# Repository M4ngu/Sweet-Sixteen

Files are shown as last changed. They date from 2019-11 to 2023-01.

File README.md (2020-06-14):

# Sweet-Sixteen
Eurorack module based in the [16n faderbank][16n-faderbank/16n]. 

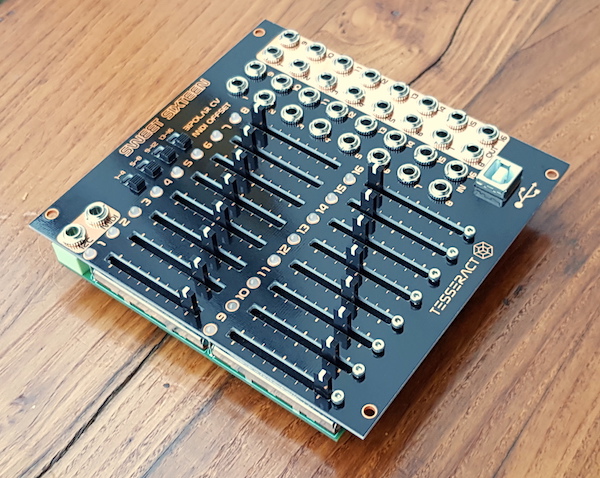
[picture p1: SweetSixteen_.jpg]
Sweet Sixteen


## The following changes were made to the original hardware:

-The PCB layout has been made from scratch, so it's totally different, with 0603 passives instead of 0805.

-A power section has been added to work within the eurorack modular synth format, with diode protection and the option to power the Teensy with an internal 5V LDO or the eurorack 5V rail (selectable with a jumper on the back of the module). The voltage to feed the faders now comes from a dedicated voltage regulator, more stable and precise than most USB voltage sources.

-16 Inputs has been added. A "default voltage" is normalled to the input jacks, so when something is plugged in, that normalization is broken, being the incomming CV attenuated by the fader. This adition makes the module to work also as 16 attenuators, Cv to Midi, Cv to i2C...

-The op-amps circuit has been modiffied, being TL074s for the CV outs and MCP6004s for the circuit that prepares the voltages to be read by the Teensy. In this version the MCP6004 are powered with 3,3V & GND (instead of the original 5V), the rail-to-rail characteristic of those op-amps provides voltage protection to the Teensy. That is specially handy for the CV inputs, as any voltage plugged in, will be limited to 3,3v by the MCP6004s. Another important modification in this part of the circuit is the addition of negative voltage references and that now is a summing inverting gain circuit (for that reason the FLIP option in the firmware is necessary for this version of the hardware, as in the minimum position of the fader the voltage readed by the Teensy will be 3,3V and in the max position it will be 0V). The TL074s are powered by +12V & -12V.

-Four slide switches has been added to swap the voltage reference (1 for every 4 faders, there was no room for 16 switches). The reason is to allow negative voltages to be coorectly converted to midi CC (or i2C). In the normal position a 0V input is traduced as minimum CC value, with the switch turned up the voltage reference is -2,5V (instead of -5V) that means that 0V input correspond to the center position of the MidiCC, positive voltages will increase the value while negative ones will decrease it.

-The output voltage of the faders (that "default voltage" normalled to the jacks) has been increassed to 8v, the original 5v seems to be not enough to work in eurorack, like to wide open-close the cutoff of a filter etc. I decided to go 8v instead of 10v because of the CV inputs. If the circuit that prepares the voltages comming from the faders to be readed by the Teensy is expecting 10v then it will be impossible to cover all the range of a MidiCC with an LFO which is ±4v (or 8v pp). For the contrary, if that circuit is expecting 8V it can not only cover the whole Midi CC range but also allows saturating the waveform if the voltage source has over 8V pp (like a 10V envelope or a ±5V LFO).

-16 bicolor leds has been added in parallel with the CV out, allowing visual feedback of what's going on each track, specially handy when using the CV inputs.

-USB type B connector pcb mounted has been also added. Those connectors are much stronger than mini or micro ones, the USB 5V pin is not connected, this way you can update the firmware of the Teensy without powering off the module.

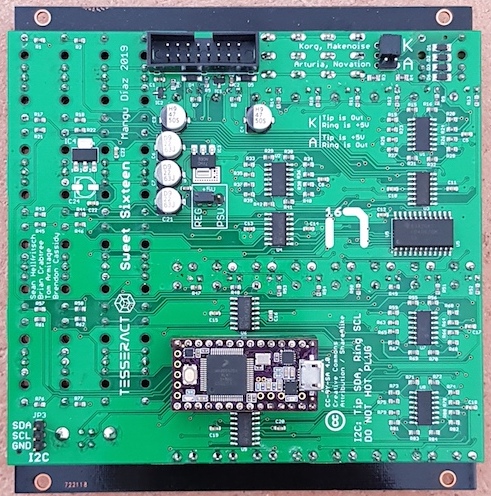
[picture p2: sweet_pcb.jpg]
PCB


Various versions of the firmware are available, all them derived from the 16n by Tom Armitage.

Manual and build guide:

https://www.tesseractmodular.com/manuals/sweet-sixteen-manual

## [firmware](firmware/)

## [hardware](hardware/)

### There are 16 faders/channels, which can be used as:

 -Midi controller.  
 -Manual CV generator (0 to 8v range).  
 -Attenuator.  
 -CV to Midi CC.  
 -i2C controller.  
 -CV to i2C data.  

### Features:

 -16 inputs.  
 -16 outputs.  
 -16 faders.  
 -16 bi-color leds to show what's going on in every channel.  
 -Midi trs out.  
 -Jumpers on the back to swap between 'Arturia/Novation'  and 'Korg/Makenoise' Midi trs standards.  
 -USB Midi out (connector type B, usb midi class compliant device).  
 -4 switches to enable bi-polar CV to Midi/i2C conversion (one for every 4 channels).  
 -i2C via mini jack on front panel and pin header on the back of the module.  

## Credits
This is a derivative work of the [16n faderbank][16n-faderbank/16n].  
Based on original work by [Brian Crabtree][tehn] and Sean Hellfritsch.  
Minijack MIDI, I2C circuitry and CV outputs by [Tom Armitage][infovore].  
Firmware by [Brian Crabtree][tehn], [Tom Armitage][infovore], and [Brendon Cassidy][bpcmusic].  
Eurorack conversion, hardware & firmware mods by Mangu Díaz 2019.  

## Licensing

Panels and electronic schematics/layouts/gerber files are licensed under
[Creative Commons Attribution Share-Alike 4.0][ccbysa].

Firmware is licensed under the [MIT License][mitlicense].

[linespost]: https://llllllll.co/t/sixteen-n-faderbank/3643
[tehn]: https://github.com/tehn
[bpcmusic]: https://github.com/bpcmusic
[infovore]: https://github.com/infovore
[octobom]: https://octopart.com/bom-tool/unJxkzvR
[ccbysa]: https://creativecommons.org/licenses/by-sa/4.0/
[mitlicense]: https://opensource.org/licenses/MIT
[16n-faderbank/16n]: https://github.com/16n-faderbank/16n

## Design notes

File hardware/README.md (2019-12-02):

If you want to order pcbs yourself make sure you have a valid replacement for the faders, the ones I use may have a weird pinout. You can also edit the board in order to use your desired fader model.

The voltage of the faders (when there's nothing plugged in) could be easy modified by replacing the IC4 for another LDO and changing the value of the summing resistors in the MCP6004 circuits, in order to get 3,3v (or close) from the LDO once passes throught the op-amp.

The formula is pretty simple: 

Vin * (RFB / RIN) = 3,3 

In this case the IC4 LDO is an 8V regulator, so: 

8v * (33k / 80,6k) = 3,27v

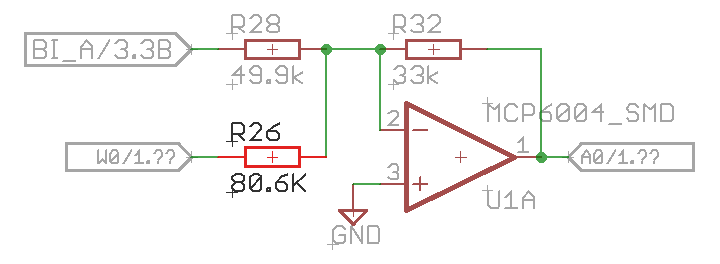
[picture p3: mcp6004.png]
MCP6004 circuit


Keep in mind that if you change the 33k feedback resistor for other value, the summing resistors for the voltage reference must be also adapted with the same criteria: 

5v * (33k / 49,9k) = 3,3v

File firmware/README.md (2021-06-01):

## Sweet_3

derived from the 16n 2.0.1 by Tom Armitage. 

midiCC, midi channels, master i2c and calibration settings can be done in the web editor so compiling your own firmware is not necessary, just download the HEX file and flash it with the Teensy loader.

https://16n-faderbank.github.io/editor/

changes from the original 16n 2.0.1:
  
  -channel numbers are not reversed if the 'rotate' is active
  
  -calibration of the high value is now possible when the 'rotate' is active

  -added pitchBend ( by selecting midiCC 127 )
  
  -added support for GESS ( Gate Expander for Sweet Sixteen ) which makes midi notes with gates & buttons in GESS
  
    About the GESS feature:
    
    -every button/gate in will create a midi note in the TRS & USB midi outs
    
    -the pitch and velocity can be a fixed value or CV controlled (upper 8 faders & CV inputs for note value, lower 
    row of fader & CV for velocity)
    
    -8 presets
    
    -press the function button (next the USB port) to activate the 'load preset', any of the 8 buttons will load it.
    
    -press the function button while pressing any of the 8 GESS buttons will save a preset, the position of the 
    faders will determine the preset values (upper row for pitch, lower row  for velocity) and if any of the faders
    is at minimum position, then that value would be read in real time. So if you save a preset with the fader 2 & 9 
    fully down, the midi notes generated by gates in the GESS input 2 will be controlled by the fader & CV 2, and the
    velocity of the notes generated by the gate input 1 will be CV controlled by fader & CV 9. None of those faders 
    will send the usual midiCC while being used for midi note or velocity.

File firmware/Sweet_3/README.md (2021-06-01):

# Sweet_3 Firmware

Designed to run on a Teensy 3.2; 

This README serves as a guide for **developing** and **compiling** your own versions of the firwmare. The recommended method for putting firmware onto a Sweet Sixteen is to use Teensy Loader directly. 

If you are interested in compiling your own firmware, or hacking on it, read on!

## Requirements

- Latest Teensyduino install.
- `ResponsiveAnalogRead` library
- `CD74HC4067` library

## Compilation

- You **must** compile this with Tools->USB type set to **MIDI**. (**Serial+MIDI** may have issues with certain devices you connect to).
- Be sure that the board speed is set to 120mhz (overclock) for maximum repsonsiveness.
- If you're having issues compiling related to MIDI libraries or code: make sure your Arduino `libraries` folder doesn't have any old versions of weird MIDI libraries in. The MIDI library should be installed by default via Teensyduino; otherwise, if you have the latest version of the 47effects MIDI library in your Libraries Manager, that'll also behave. It turns out that older versions in the legacy `libraries` folder sometimes lead to conflicts.

## Customisation and configuration

As of 16n firmware 2.0.0, you no longer should do ANY configuration through the Arduino IDE. Most configurations are conducted from a web browser, using the [16n editor][editor]

The Sweet Sixteen will be initialised to a set of default settings (All outputs for TRS and USB set to MIDI channel 1, CCs 32-47, I2C set to Leader). Once this is done, connect over USB, and go to the [editor][editor] in Google Chrome; you will be able to see the current configuration, edit the configuration, and transmit the new config to your device. You will likely need to customise the maximum fader value calibrations.

Note that if you do change any config related to I2C, you should power-cycle the 16n before it will be picked up.

Some options _do_ remain in `config.h`; they are for developers to specify options that are likely to need setting once, or adjusting during the development process:

In `config.h`

// define startup delay in milliseconds

// for ER-301, which needs to be ON before Sweet Sixteen to connect via i2c

#define BOOTDELAY 10000

// uncomment this to allow PITCHBEND for controller 127:

#define PITCHBEND 1

// allow the Tsesseract Modular GESS & midi note implementation:

#define GESS 1

// default GESS settings (midi note, velocity and channel):

byte _nNote[8] = { 30, 40, 50, 60, 70, 80, 90, 100 };

byte _nVelocity[8] = { 120, 120, 120, 120, 120, 120, 120, 120 };

byte _nChannel[8] = { 1, 2, 3, 4, 5, 6, 7, 8 };

```C
#define DEBUG 1
```

will log debug messages to the serial port.

```C
#define DEV 1
```

will restrict the faderbank to its first channel. Designed for breadboard development; almost certainly not of interest.

## Memory Map

Configuration is stored in the first 80 bytes of the on-board EEPROM. It looks like this:

Addresses 0-15 are reserved for configuration flags/data.

FADERMAX and FADERMIN are 14-bit numbers; as such, they are stored in two bytes as MSB and LSB; the actual number is calculated by `(MSB << 8) + LSB`

+---------+--------+------------------------------------+

| Address | Format |            Description             |

+---------+--------+------------------------------------+

| 0       | 0/1    | LED on when powered                |

| 1       | 0/1    | LED blink on MIDI data             |

| 2       | 0/1    | Rotate controller outputs via 180º |

| 3       | 0/1    | I2C Master/Follower                |

| 4,5     | 0-127  | FADERMIN lsb/msb                   |

| 6,7     | 0-127  | FADERMAX lsb/msb                   |

| 8-15    |        | Currently vacant                   |

+---------+--------+------------------------------------+

| 16-31   | 0-15   | Channel for each control (USB)     |

| 32-47   | 0-15   | Channel for each control (TRS)     |

| 48-63   | 0-127  | CC for each control (USB)          |

| 64-79   | 0-127  | CC for each control (TRS)          |

+---------+--------+------------------------------------+

EEPROM address 100-115 is used for GESS presets

## LICENSING

see `LICENSE`

[load-firmware]: https://github.com/16n-faderbank/16n/wiki/Firmware:-installation-instructions
[editor]: https://16n-faderbank.github.io/editor

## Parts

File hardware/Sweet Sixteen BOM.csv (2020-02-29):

Qty | DESIGNATOR | FOOTPRINT | COMMENT | Description | MF
2 | R3, R4 | 0805-R | 47 | RESISTOR, European symbol
2 | R5, R6 | 0603-R | 270 | RESISTOR, American symbol
16 | R1, R2, R17, R18, R21, R22, R43, R44, R45, R46, R57, R58, R61, R62, R76, R77 | 0603-R | 1K | RESISTOR, European symbol
16 | R7, R8, R9, R10, R11, R12, R13, R14, R47, R48, R49, R50, R51, R52, R53, R54 | 0603-R | 10k | RESISTOR, European symbol
16 | R15, R16, R29, R30, R31, R32, R41, R42, R55, R56, R69, R70, R71, R72, R83, R84 | 0603-R | 33k | RESISTOR, European symbol
16 | R19, R20, R27, R28, R33, R34, R39, R40, R59, R60, R67, R68, R73, R74, R81, R82 | 0603-R | 49.9k | RESISTOR, European symbol
1 | R26 | 0603-R | 50K | RESISTOR, European symbol
15 | R23, R24, R25, R35, R36, R37, R38, R63, R64, R65, R66, R75, R78, R79, R80 | 0603-R | 80.6k | RESISTOR, European symbol
11 | C5, C10, C11, C12, C13, C14, C15, C16, C18, C19, C20, C8, C17, C9, C22 | 0603-C | 100n | CAPACITOR, European symbol
1 | C23 | 0603-C | 330n | CAPACITOR, American symbol
2 | C1, C2 | 0603-C | 470n | CAPACITOR, American symbol
1 | C24 | PANASONIC_C | 10u | POLARIZED CAPACITOR, American symbol
3 | C6, C7, C21 | PANASONIC_D | 22u | POLARIZED CAPACITOR, American symbol
2 | C3, C4 | PANASONIC_D | 47u | POLARIZED CAPACITOR, American symbol
4 | D1, D2, D3, D6 | SOD-123 | 1N4148
2 | D4, D5 | SOD123 | 1N5819 | DIODE
1 | IC3 | SOT223 | LM1117-5 | 800mA and 1A Low Dropout (LDO) Positive Regulator
1 | IC1 | DBZ_R-PDSO-G3 | LM4040C25 | PRECISION MICROPOWER SHUNT VOLTAGE REFERENCE
1 | IC2 | DBZ_R-PDSO-G3 | LM4040c50 | PRECISION MICROPOWER SHUNT VOLTAGE REFERENCE
1 | IC4 | SOT223 | UA78M08DCY | 8V POSITIVE-VOLTAGE REGULATORS
1 | U5 | SOIC127P1030X265-24 | CD74HC4067SM96 | 16-channel analog MUX
4 | U1, U2, U7, U8 | SO14 | MCP6004_SMD | Generic Quad Op Amp
4 | U3, U4, U6, U9 | SO14 | TL074_SMD | Generic Quad Op Amp
1 | TENSY3.2 | TEENSY_3.0-3.2&LC_DIL | TEENSY_3.1-3.2_DIL | Teensy 3.1 or 3.2 in a DIL Layout.
34 | J1, J2, J3, J4, J5, J6, J7, J8, J9, J10, J11, J12, J13, J14, J15, J16, J17, J18, J19, J20, J21, J22, J23, J24, J25, J26, J27, J28, J29, J30, J31, J32, J33, J34 | WQP_PJ_301M6 | PJ301_THONKICONN6
1 | X1 | KUSBVX-BS1N | KUSBVX-BS1N | USB B-type Receptacle Vertical, 4 Position, Through Hole
2 | +5V, JP3 | 1X03 |  | PIN HEADER
1 | JP1 | 2X03 |  | PIN HEADER
16 | TM1, TM2, TM3, TM4, TM5, TM6, TM7, TM8, TM9, TM10, TM11, TM12, TM13, TM14, TM15, TM16 | SLIDEPOT-45 |  | Sliding potentiometers
4 | S1, S2, S3, S4 |  |  | SLIDING SWITCH
16 | LED1, LED2, LED3, LED4, LED5, LED6, LED7, LED8, LED9, LED10, LED11, LED12, LED13, LED14, LED15, LED16 | LED3MM |  | BI-COLOR LED
1 | SV1 | ML16 |  | HARTING

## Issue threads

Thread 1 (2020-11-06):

Usb undefined

synnys, 2020-11-06:
I’m flashed my teensy, the sweet sixteen is working fine. But when I connect the usb b port to my computer, my Mac sees it as “undefined” and it’s not receiving any midi. Any idea what this could be? The flashing went fine

M4ngu, 2020-11-06:
Hi there, did you set the USB as MIDI?
and CPU to 120mhz?
https://www.tesseractmodular.com/manuals/sweet-sixteen-manual#h.p_RE-CxcQ3ERIl
let me know if this helps
Mangu Díaz - Tesseract Modular
https://www.tesseractmodular.com/
https://www.facebook.com/Tesseract-Modular-146727136274298
https://www.modulargrid.net/e/vendors/view/713
https://www.instagram.com/mangudiaz/

El vie., 6 nov. 2020 a las 21:39, synnys (<notifications@github.com>)
escribió:

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

synnys, 2020-11-06:
Yes I did set it as usb midi @ 120mhz

Ruben Hulzebosch

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

synnys, 2020-11-06:
do I need to install additional libraries in teensyduino? Because it doesn't error on compile..

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
these .h includes have a different color though, not sure if that's supposed to be like that?

M4ngu, 2020-11-07:
to compile it you have to download all files in the folder, not just the
.ino file,
those files included in the folder are the green ones,
the other are libraries,
if it compiles with no errors it's all correct, you don't need to install
any extra library or download any file,

Which firmware are you installing?
my recommendation is the 2.0.1 version modded for SweetSixteen,  because
the settings can be modified with web application,
unless you have the GESS or you need pitch bend, in that case the other
firmwares would be better,
I think there is a compiled version of that, let me know if you can't find
it
all the best
Mangu Díaz - Tesseract Modular
https://www.tesseractmodular.com/
https://www.facebook.com/Tesseract-Modular-146727136274298
https://www.modulargrid.net/e/vendors/view/713
https://www.instagram.com/mangudiaz/

El vie., 6 nov. 2020 a las 23:15, synnys (<notifications@github.com>)
escribió:

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

synnys, 2020-11-08:
I cloned the whole repository so I did have all the files, not just the .ino file.
I uploaded this firmware: https://github.com/M4ngu/Sweet-Sixteen/tree/master/firmware/Sweet_mkII/_16n_faderbank_firmware_Sweet_mkII
(since I have an mk2)
I had no compiler errors and the flashing went fine, I just can't seem to figure out why it's not detected as a USB midi device. It just sees it as undefined... If you have a compiled .hex I could try that would be great

Cheers.

synnys, 2020-11-08:
Hmm come to think of it, I suddenly have a feeling i know what might have gone wrong...
In the BOM this was the USB connector: https://nl.mouser.com/datasheet/2/670/uj2_bv_1_th-1779281.pdf
However, that was not in stock so I ordered this one in the meantime, while the other in back stock would be delivered: https://nl.mouser.com/ProductDetail/530-SS-52300-002

I just saw that it has a reverse orientation compared to the one in the BOM, so I suspect the pinout is upside down then as well....

M4ngu, 2020-11-08:
so you have the GESS expander correct?
because if not I'd recommend the 2.0.1 version.

I thought all those USB connectors had the same pinout, anyway I can't see
that info in the specs sheet of one of them :-(
but as you say, the orientation is different, so pins may be also
different, but can't say 100% sure.

To be sure that the USB is working what I do is just to flash the Teensy
using the front USB port, with the module powered, if it flashes ok then
the USB is going fine,
the computer should detect it as a "16n" midi device if everything is
correct.

there you have a compiled HEX from that mkII version,

let me know if it helps

 best
Mangu Díaz - Tesseract Modular
https://www.tesseractmodular.com/
https://www.facebook.com/Tesseract-Modular-146727136274298
https://www.modulargrid.net/e/vendors/view/713
https://www.instagram.com/mangudiaz/

El dom., 8 nov. 2020 a las 10:40, synnys (<notifications@github.com>)
escribió:

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

synnys, 2020-11-20:
installed new USB connector, since i foolishly damaged the original one. (Desoldering was a drama for some reason)
Installed the 2.0.1 firmware, all is workingas it should now and the web-editor is working too.
Case closed!
Thanks for the help.

Ruben

Closed 2020-11-20.

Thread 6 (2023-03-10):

MIDI to CV

Bubobubobubobubo, 2023-03-10:
Hi,

Is it possible to reprogram the Sweet Sixteen to act as a MIDI to CV converter? I would like to use the same CC values but in the other direction :) Meaning, a CC from 0 to 127 converted into a 0-8V on the corresponding output. If so, could you provide some guidance on the process to rewrite the code to do so?

Thanks a lot, nice module!

M4ngu, 2023-03-11:
The digital part of this module controls only the MIDI and the i2C data. The faders, CV in & out circuit is fully analog, so modifications like changing the output voltage range can’t be done via firmware.
This module can do CV to midi (among many other functions) NOT midi to CV.

Bubobubobubobubo, 2023-03-11:
OK! Thanks!

Closed 2023-03-11.

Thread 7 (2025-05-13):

GESS i2c "0x00" shown on ES Disting NT

zstadl, 2025-05-13:
Hi there,

I'm having a hard time getting the GESS to work via i2c with my disting NT. The SW16 works fine with the disting NT. I get the messages on the disting's i2c monitor with the following format when I move a fader: 0x11 0x... ...x... ...x... However, when I press a button on the GESS i get the following on the Disting NT: 0x00.

It seems like the GESS doesn't send messages that the Disting NT can read. Also, when inspecting your firmware (correct me if I'm wrong) the GESS button midi to i2c messaging only work on the ER301: https://github.com/M4ngu/Sweet-Sixteen/commit/ed8b34c4b99a08bfd41c659a50852e556b334f12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

What do I need to change in order to make the GESS button i2c thingy work for the Disting NT?

Thx a lot!

ralbring, 2025-05-13:
Oh i think thats not so easy. I dosent tested or programmed this for disting NT. there are more problems.
1) The code must be compiled with the config.h option GESS 1. Default is off!
2) The Adresses for the disting at the i2c bus must inserted and used in the code and changed so that the message and variable er301Present is set to true.
If the code is not compiled with Option GESS or the address to the slave at the i2c bus ist correct, so that this is initilized no messege will be go out.

The first think that i woud try is to change the i2c address so that is correct and the initilizing part foud the device. All other stuff must be changed later and meybe it is a god style to bring the new constants for the disting into the code.

zstadl, 2025-05-13:
thanks a lot for the answer.

I followed your steps:
on config.h:
```
// allow the Tsesseract Modular GESS & midi note implementation:
#define GESS 1

// treat a Disting NT on the bus exactly like the ER-301 expander:
static const bool    er301Present     = true;   // enable GESS at compile time
static const uint8_t er301I2Caddress  = 0x31;   // Disting NT’s default I²C address
```

on the Sweet_3.ino I introduced a new i2c channel:
`#define TO_GATE 0x20 `

and applied it under the doMidiWrite section:
```
#ifdef GESS
    // Midi Note
    if ((q > 7) && (_G[q - 8] != old_G[q - 8])) // only if the gate input has changed we do this:
    {
      k = ( q - 8) ;
      if ( _G[k] == LOW ) //note ON
      {
        if (nNote[k] == true) // taking the note value from the upper row of faders instead of a fixed value
        {
          _nNote[k] = lastMidiValue[k];
        }
        if (nVelocity[k] == true) // taking the midi velocity from the lower row instead instead of a fixed value
        {
          _nVelocity[k] = lastMidiValue[q];
        }
        MIDI.sendNoteOn(_nNote[k], _nVelocity[k], _nChannel[k] ); // at the moment channels are 1 to 8 preassigned
        usbMIDI.sendNoteOn(_nNote[k], _nVelocity[k], _nChannel[k] );
        // ER-301
        if (er301Present) {
          // https://github.com/odevices/er-301/blob/develop/mods/teletype/Dispatcher.cpp
          // SC.TR 1-n α --> Set TR value to α (0/1)
          // commandTRSet(delay, getPort(msg), getValue(msg));
          sendi2c(er301I2Caddress, 0, TO_GATE, q - 8, 1);
        }

      }
      else //Note Off
      {
        MIDI.sendNoteOff(_nNote[k], _nVelocity[k], _nChannel[k] );
        usbMIDI.sendNoteOff(_nNote[k], _nVelocity[k], _nChannel[k] );
        if (er301Present) {
          sendi2c(er301I2Caddress, 0, TO_GATE, q - 8, 0);
        }

      }
      old_G[k] = _G[k];
    }  //end of midi note code
#endif
```

Good News: i2c monitoring on the Disting show "0x20"!
Bad news: That's all I see. No: "q - 8, 1" or "q - 8, 0".

Do you have an idea why?

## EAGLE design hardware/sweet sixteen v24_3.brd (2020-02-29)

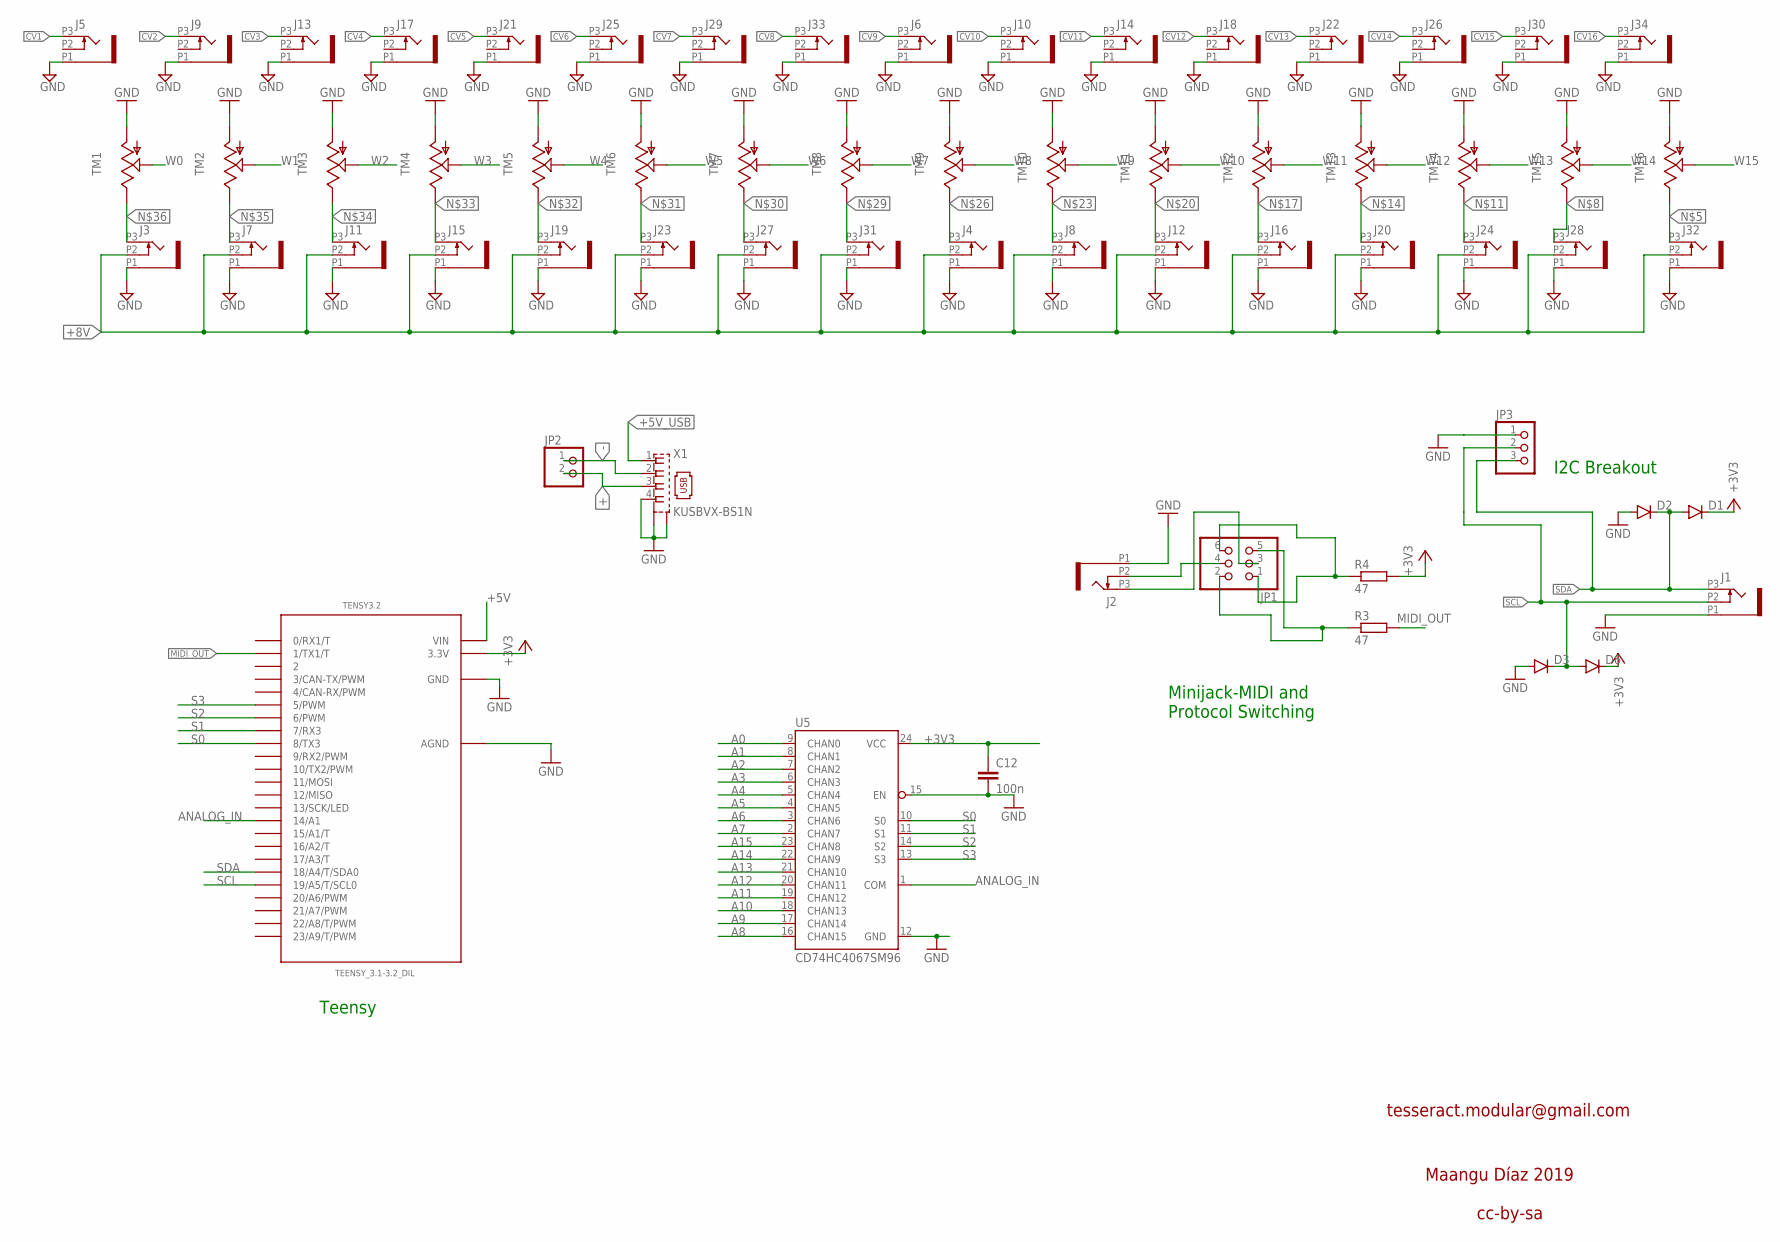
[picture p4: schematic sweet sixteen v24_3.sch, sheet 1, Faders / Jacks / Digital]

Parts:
C12: 100n; C0603
D1, D2, D3, D6: DIODESOD123; SOD-123
J1, J2, J3, J4, J5, J6, J7, J8, J9, J10, J11, J12, J13, J14, J15, J16, J17, J18, J19, J20, J21, J22, J23, J24, J25, J26, J27, J28, J29, J30, J31, J32, J33, J34: PJ301_THONKICONN6; WQP_PJ_301M6
JP1: PINHD-2X3; 2X03
JP2: PINHD-1X2; 1X02
JP3: PINHD-1X3; 1X03
R3, R4: 47; R0805
TENSY3.2: TEENSY_3.1-3.2_DIL; TEENSY_3.0-3.2&LC_DIL
TM1, TM2, TM3, TM4, TM5, TM6, TM7, TM8, TM9, TM10, TM11, TM12, TM13, TM14, TM15, TM16: TRIMSLIDE45; SLIDEPOT-45
U5: CD74HC4067SM96; SOIC127P1030X265-24
X1: KUSBVX-BS1N

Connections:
+: JP2.2, X1.3
+3V3: C12.1, D1.C, D6.C, R4.2, TENSY3.2.3.3V, U5.24 (VCC); also elsewhere on the board
+5V: TENSY3.2.VIN; also elsewhere on the board
+5V_USB: X1.1
+8V: J3.P2 (2), J4.P2 (2), J7.P2 (2), J8.P2 (2), J11.P2 (2), J12.P2 (2), J15.P2 (2), J16.P2 (2), J19.P2 (2), J20.P2 (2), J23.P2 (2), J24.P2 (2), J27.P2 (2), J28.P2 (2), J31.P2 (2), J32.P2 (2); also elsewhere on the board
-: JP2.1, X1.2
A0: U5.9 (CHAN0); also elsewhere on the board
A1: U5.8 (CHAN1); also elsewhere on the board
A2: U5.7 (CHAN2); also elsewhere on the board
A3: U5.6 (CHAN3); also elsewhere on the board
A4: U5.5 (CHAN4); also elsewhere on the board
A5: U5.4 (CHAN5); also elsewhere on the board
A6: U5.3 (CHAN6); also elsewhere on the board
A7: U5.2 (CHAN7); also elsewhere on the board
A8: U5.16 (CHAN15); also elsewhere on the board
A9: U5.17 (CHAN14); also elsewhere on the board
A10: U5.18 (CHAN13); also elsewhere on the board
A11: U5.19 (CHAN12); also elsewhere on the board
A12: U5.20 (CHAN11); also elsewhere on the board
A13: U5.21 (CHAN10); also elsewhere on the board
A14: U5.22 (CHAN9); also elsewhere on the board
A15: U5.23 (CHAN8); also elsewhere on the board
ANALOG_IN: TENSY3.2.14/A0 (14/A1), U5.1 (COM)
CV1: J5.P3 (3); also elsewhere on the board
CV2: J9.P3 (3); also elsewhere on the board
CV3: J13.P3 (3); also elsewhere on the board
CV4: J17.P3 (3); also elsewhere on the board
CV5: J21.P3 (3); also elsewhere on the board
CV6: J25.P3 (3); also elsewhere on the board
CV7: J29.P3 (3); also elsewhere on the board
CV8: J33.P3 (3); also elsewhere on the board
CV9: J6.P3 (3); also elsewhere on the board
CV10: J10.P3 (3); also elsewhere on the board
CV11: J14.P3 (3); also elsewhere on the board
CV12: J18.P3 (3); also elsewhere on the board
CV13: J22.P3 (3); also elsewhere on the board
CV14: J26.P3 (3); also elsewhere on the board
CV15: J30.P3 (3); also elsewhere on the board
CV16: J34.P3 (3); also elsewhere on the board
GND: C12.2, D2.A, D3.A, J1.P1 (1), J2.P1 (1), J3.P1 (1), J4.P1 (1), J5.P1 (1), J6.P1 (1), J7.P1 (1), J8.P1 (1), J9.P1 (1), J10.P1 (1), J11.P1 (1), J12.P1 (1), J13.P1 (1), J14.P1 (1), J15.P1 (1), J16.P1 (1), J17.P1 (1), J18.P1 (1), J19.P1 (1), J20.P1 (1), J21.P1 (1), J22.P1 (1), J23.P1 (1), J24.P1 (1), J25.P1 (1), J26.P1 (1), J27.P1 (1), J28.P1 (1), J29.P1 (1), J30.P1 (1), J31.P1 (1), J32.P1 (1), J33.P1 (1), J34.P1 (1), JP3.1, TENSY3.2.AGND, TENSY3.2.GND, TM1.A, TM2.A, TM3.A, TM4.A, TM5.A, TM6.A, TM7.A, TM8.A, TM9.A, TM10.A, TM11.A, TM12.A, TM13.A, TM14.A, TM15.A, TM16.A, U5.12 (GND), U5.15 (EN), X1.4, X1.M1 (S1), X1.M2 (S2); also elsewhere on the board
MIDI_OUT: R3.2, TENSY3.2.1 (1/TX1/T)
unnamed: J2.P3 (3), JP1.3
unnamed: J2.P2 (2), JP1.4
unnamed: JP1.2, JP1.5, R3.1
unnamed: JP1.1, JP1.6, R4.1
unnamed: J32.P3 (3), TM16.B
unnamed: J28.P3 (3), TM15.B
unnamed: J24.P3 (3), TM14.B
unnamed: J20.P3 (3), TM13.B
unnamed: J16.P3 (3), TM12.B
unnamed: J12.P3 (3), TM11.B
unnamed: J8.P3 (3), TM10.B
unnamed: J4.P3 (3), TM9.B
unnamed: J31.P3 (3), TM8.B
unnamed: J27.P3 (3), TM7.B
unnamed: J23.P3 (3), TM6.B
unnamed: J19.P3 (3), TM5.B
unnamed: J15.P3 (3), TM4.B
unnamed: J11.P3 (3), TM3.B
unnamed: J7.P3 (3), TM2.B
unnamed: J3.P3 (3), TM1.B
S0: TENSY3.2.8 (8/TX3), U5.10 (S0)
S1: TENSY3.2.7 (7/RX3), U5.11 (S1)
S2: TENSY3.2.6 (6/PWM), U5.14 (S2)
S3: TENSY3.2.5 (5/PWM), U5.13 (S3)
SCL: D3.C, D6.A, J1.P2 (2), JP3.2, TENSY3.2.19/A5 (19/A5/T/SCL0)
SDA: D1.A, D2.C, J1.P3 (3), JP3.3, TENSY3.2.18/A4 (18/A4/T/SDA0)
W0: TM1.WIPER; also elsewhere on the board
W1: TM2.WIPER; also elsewhere on the board
W2: TM3.WIPER; also elsewhere on the board
W3: TM4.WIPER; also elsewhere on the board
W4: TM5.WIPER; also elsewhere on the board
W5: TM6.WIPER; also elsewhere on the board
W6: TM7.WIPER; also elsewhere on the board
W7: TM8.WIPER; also elsewhere on the board
W8: TM9.WIPER; also elsewhere on the board
W9: TM10.WIPER; also elsewhere on the board
W10: TM11.WIPER; also elsewhere on the board
W11: TM12.WIPER; also elsewhere on the board
W12: TM13.WIPER; also elsewhere on the board
W13: TM14.WIPER; also elsewhere on the board
W14: TM15.WIPER; also elsewhere on the board
W15: TM16.WIPER; also elsewhere on the board

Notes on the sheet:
Teensy
Minijack-MIDI and Protocol Switching
I2C Breakout
cc-by-sa
Maangu Díaz 2019
tesseract.modular@gmail.com

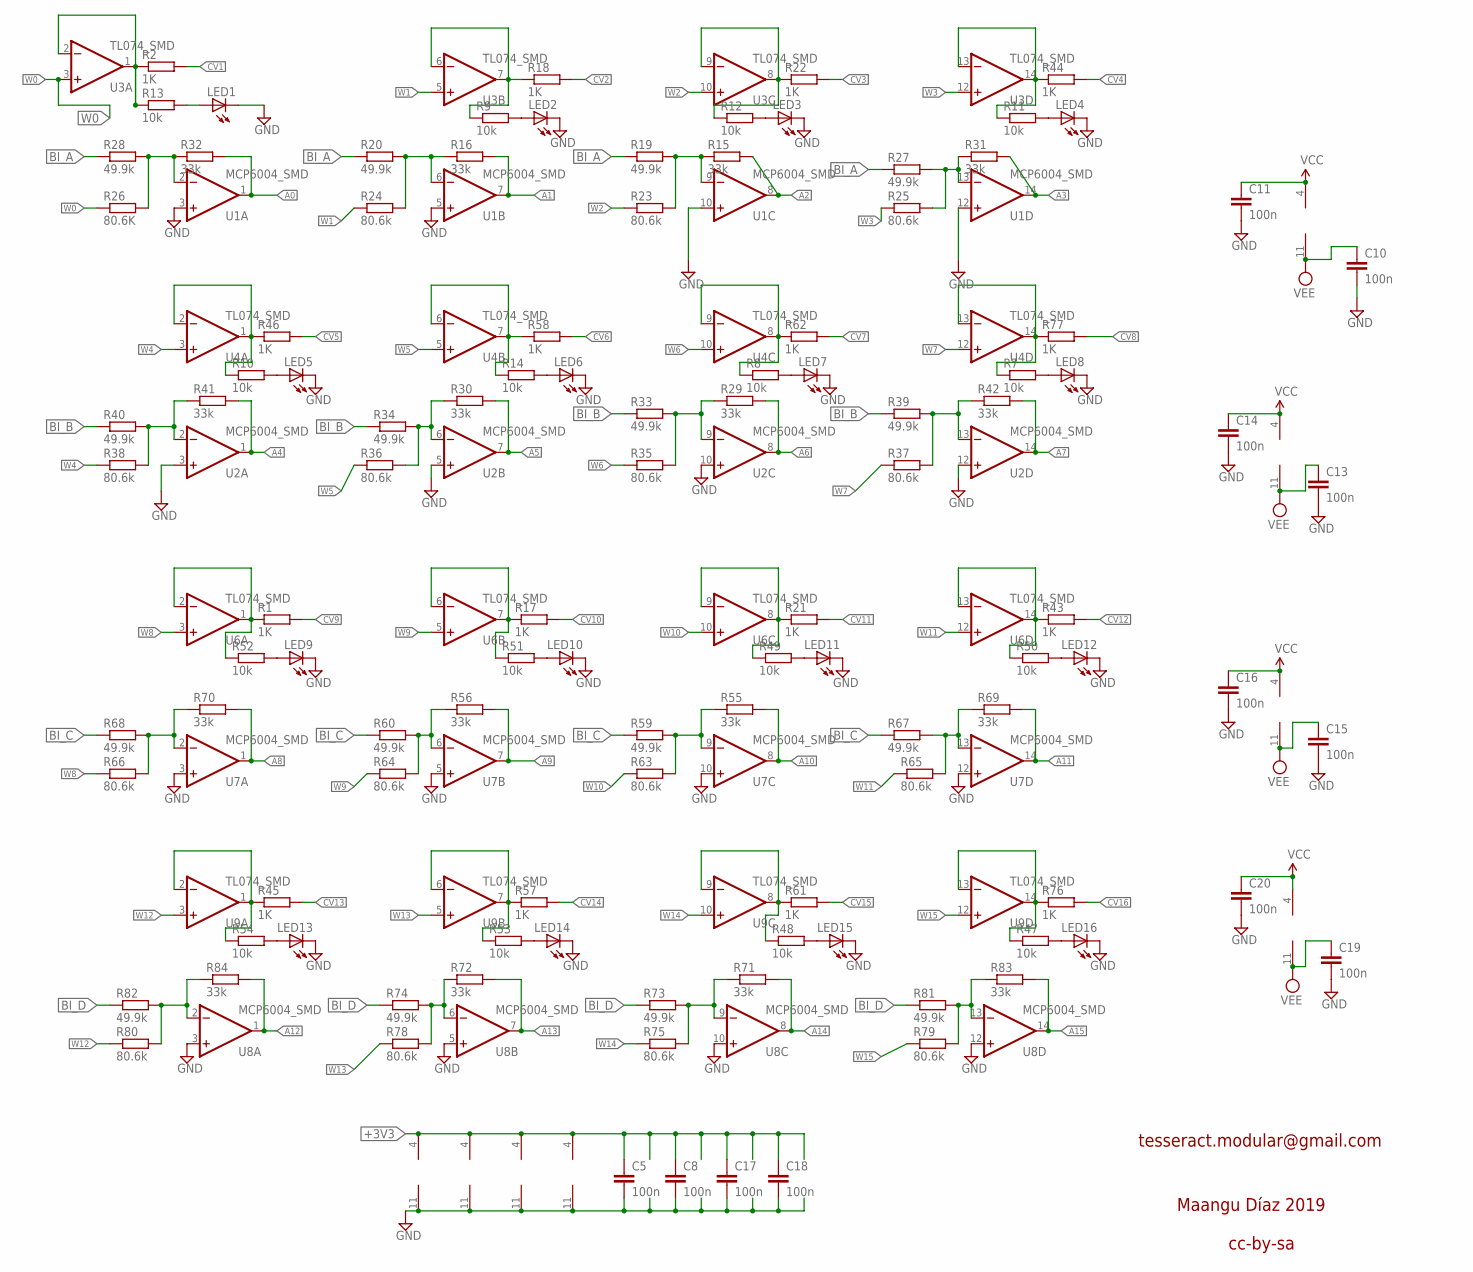
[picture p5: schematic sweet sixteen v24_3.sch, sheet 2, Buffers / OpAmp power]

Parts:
C5, C10, C11, C13, C14, C15, C16, C18, C19, C20: 100n; C0603
C8, C17: 100n; C0603K
LED1, LED2, LED3, LED4, LED5, LED6, LED7, LED8, LED9, LED10, LED11, LED12, LED13, LED14, LED15, LED16: LED3MM
R1, R2, R17, R18, R21, R22, R43, R44, R45, R46, R57, R58, R61, R62, R76, R77: 1K; R0603
R7, R8, R9, R10, R11, R12, R13, R14, R47, R48, R49, R50, R51, R52, R53, R54: 10k; R0603
R15, R16, R29, R30, R31, R32, R41, R42, R55, R56, R69, R70, R71, R72, R83, R84: 33k; R0603
R19, R20, R27, R28, R33, R34, R39, R40, R59, R60, R67, R68, R73, R74, R81, R82: 49.9k; R0603
R23, R24, R25, R35, R36, R37, R38, R63, R64, R65, R66, R75, R78, R79, R80: 80.6k; R0603
R26: 80.6K; R0603
U1, U2, U7, U8: MCP6004_SMD; SO14
U3, U4, U6, U9: TL074_SMD; SO14

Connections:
+3V3: C5.1, C8.1, C17.1, C18.1, U1.4 (V+), U2.4 (V+), U7.4 (V+), U8.4 (V+); also elsewhere on the board
A0: R32.2, U1.1 (OUT); also elsewhere on the board
A1: R16.2, U1.7 (OUT); also elsewhere on the board
A2: R15.2, U1.8 (OUT); also elsewhere on the board
A3: R31.2, U1.14 (OUT); also elsewhere on the board
A4: R41.2, U2.1 (OUT); also elsewhere on the board
A5: R30.2, U2.7 (OUT); also elsewhere on the board
A6: R29.2, U2.8 (OUT); also elsewhere on the board
A7: R42.2, U2.14 (OUT); also elsewhere on the board
A8: R70.2, U7.1 (OUT); also elsewhere on the board
A9: R56.2, U7.7 (OUT); also elsewhere on the board
A10: R55.2, U7.8 (OUT); also elsewhere on the board
A11: R69.2, U7.14 (OUT); also elsewhere on the board
A12: R84.2, U8.1 (OUT); also elsewhere on the board
A13: R72.2, U8.7 (OUT); also elsewhere on the board
A14: R71.2, U8.8 (OUT); also elsewhere on the board
A15: R83.2, U8.14 (OUT); also elsewhere on the board
BI_A: R19.1, R20.1, R27.1, R28.1; also elsewhere on the board
BI_B: R33.1, R34.1, R39.1, R40.1; also elsewhere on the board
BI_C: R59.1, R60.1, R67.1, R68.1; also elsewhere on the board
BI_D: R73.1, R74.1, R81.1, R82.1; also elsewhere on the board
CV1: R2.2; also elsewhere on the board
CV2: R18.2; also elsewhere on the board
CV3: R22.2; also elsewhere on the board
CV4: R44.2; also elsewhere on the board
CV5: R46.2; also elsewhere on the board
CV6: R58.2; also elsewhere on the board
CV7: R62.2; also elsewhere on the board
CV8: R77.2; also elsewhere on the board
CV9: R1.2; also elsewhere on the board
CV10: R17.2; also elsewhere on the board
CV11: R21.2; also elsewhere on the board
CV12: R43.2; also elsewhere on the board
CV13: R45.2; also elsewhere on the board
CV14: R57.2; also elsewhere on the board
CV15: R61.2; also elsewhere on the board
CV16: R76.2; also elsewhere on the board
GND: C5.2, C8.2, C10.2, C11.2, C13.2, C14.2, C15.2, C16.2, C17.2, C18.2, C19.2, C20.2, LED1.K (C), LED2.K (C), LED3.K (C), LED4.K (C), LED5.K (C), LED6.K (C), LED7.K (C), LED8.K (C), LED9.K (C), LED10.K (C), LED11.K (C), LED12.K (C), LED13.K (C), LED14.K (C), LED15.K (C), LED16.K (C), U1.3 (+IN), U1.5 (+IN), U1.10 (+IN), U1.11 (V-), U1.12 (+IN), U2.3 (+IN), U2.5 (+IN), U2.10 (+IN), U2.11 (V-), U2.12 (+IN), U7.3 (+IN), U7.5 (+IN), U7.10 (+IN), U7.11 (V-), U7.12 (+IN), U8.3 (+IN), U8.5 (+IN), U8.10 (+IN), U8.11 (V-), U8.12 (+IN); also elsewhere on the board
unnamed: R15.1, R19.2, R23.2, U1.9 (-IN)
unnamed: R25.2, R27.2, R31.1, U1.13 (-IN)
unnamed: R26.2, R28.2, R32.1, U1.2 (-IN)
unnamed: R16.1, R20.2, R24.2, U1.6 (-IN)
unnamed: R38.2, R40.2, R41.1, U2.2 (-IN)
unnamed: R30.1, R34.2, R36.2, U2.6 (-IN)
unnamed: R29.1, R33.2, R35.2, U2.9 (-IN)
unnamed: R37.2, R39.2, R42.1, U2.13 (-IN)
unnamed: R80.2, R82.2, R84.1, U8.2 (-IN)
unnamed: LED1.A, R13.2
unnamed: R71.1, R73.2, R75.2, U8.9 (-IN)
unnamed: R79.2, R81.2, R83.1, U8.13 (-IN)
unnamed: R66.2, R68.2, R70.1, U7.2 (-IN)
unnamed: LED2.A, R9.2
unnamed: R56.1, R60.2, R64.2, U7.6 (-IN)
unnamed: R55.1, R59.2, R63.2, U7.9 (-IN)
unnamed: R65.2, R67.2, R69.1, U7.13 (-IN)
unnamed: LED3.A, R12.2
unnamed: LED4.A, R11.2
unnamed: LED8.A, R7.2
unnamed: LED7.A, R8.2
unnamed: LED6.A, R14.2
unnamed: LED5.A, R10.2
unnamed: LED9.A, R52.2
unnamed: LED10.A, R51.2
unnamed: LED11.A, R49.2
unnamed: LED12.A, R50.2
unnamed: LED13.A, R54.2
unnamed: LED14.A, R53.2
unnamed: LED15.A, R48.2
unnamed: R72.1, R74.2, R78.2, U8.6 (-IN)
unnamed: LED16.A, R47.2
unnamed: R2.1, R13.1, U3.1 (OUT), U3.2 (-IN)
unnamed: R9.1, R18.1, U3.6 (-IN), U3.7 (OUT)
unnamed: R12.1, R22.1, U3.8 (OUT), U3.9 (-IN)
unnamed: R11.1, R44.1, U3.13 (-IN), U3.14 (OUT)
unnamed: R10.1, R46.1, U4.1 (OUT), U4.2 (-IN)
unnamed: R14.1, R58.1, U4.6 (-IN), U4.7 (OUT)
unnamed: R8.1, R62.1, U4.8 (OUT), U4.9 (-IN)
unnamed: R7.1, R77.1, U4.13 (-IN), U4.14 (OUT)
unnamed: R1.1, R52.1, U6.1 (OUT), U6.2 (-IN)
unnamed: R17.1, R51.1, U6.6 (-IN), U6.7 (OUT)
unnamed: R21.1, R49.1, U6.8 (OUT), U6.9 (-IN)
unnamed: R43.1, R50.1, U6.13 (-IN), U6.14 (OUT)
unnamed: R45.1, R54.1, U9.1 (OUT), U9.2 (-IN)
unnamed: R53.1, R57.1, U9.6 (-IN), U9.7 (OUT)
unnamed: R48.1, R61.1, U9.8 (OUT), U9.9 (-IN)
unnamed: R47.1, R76.1, U9.13 (-IN), U9.14 (OUT)
VCC: C11.1, C14.1, C16.1, C20.1, U3.4 (V+), U4.4 (V+), U6.4 (V+), U9.4 (V+); also elsewhere on the board
VEE: C10.1, C13.1, C15.1, C19.1, U3.11 (V-), U4.11 (V-), U6.11 (V-), U9.11 (V-); also elsewhere on the board
W0: R26.1, U3.3 (+IN); also elsewhere on the board
W1: R24.1, U3.5 (+IN); also elsewhere on the board
W2: R23.1, U3.10 (+IN); also elsewhere on the board
W3: R25.1, U3.12 (+IN); also elsewhere on the board
W4: R38.1, U4.3 (+IN); also elsewhere on the board
W5: R36.1, U4.5 (+IN); also elsewhere on the board
W6: R35.1, U4.10 (+IN); also elsewhere on the board
W7: R37.1, U4.12 (+IN); also elsewhere on the board
W8: R66.1, U6.3 (+IN); also elsewhere on the board
W9: R64.1, U6.5 (+IN); also elsewhere on the board
W10: R63.1, U6.10 (+IN); also elsewhere on the board
W11: R65.1, U6.12 (+IN); also elsewhere on the board
W12: R80.1, U9.3 (+IN); also elsewhere on the board
W13: R78.1, U9.5 (+IN); also elsewhere on the board
W14: R75.1, U9.10 (+IN); also elsewhere on the board
W15: R79.1, U9.12 (+IN); also elsewhere on the board

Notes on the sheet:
cc-by-sa
Maangu Díaz 2019
tesseract.modular@gmail.com

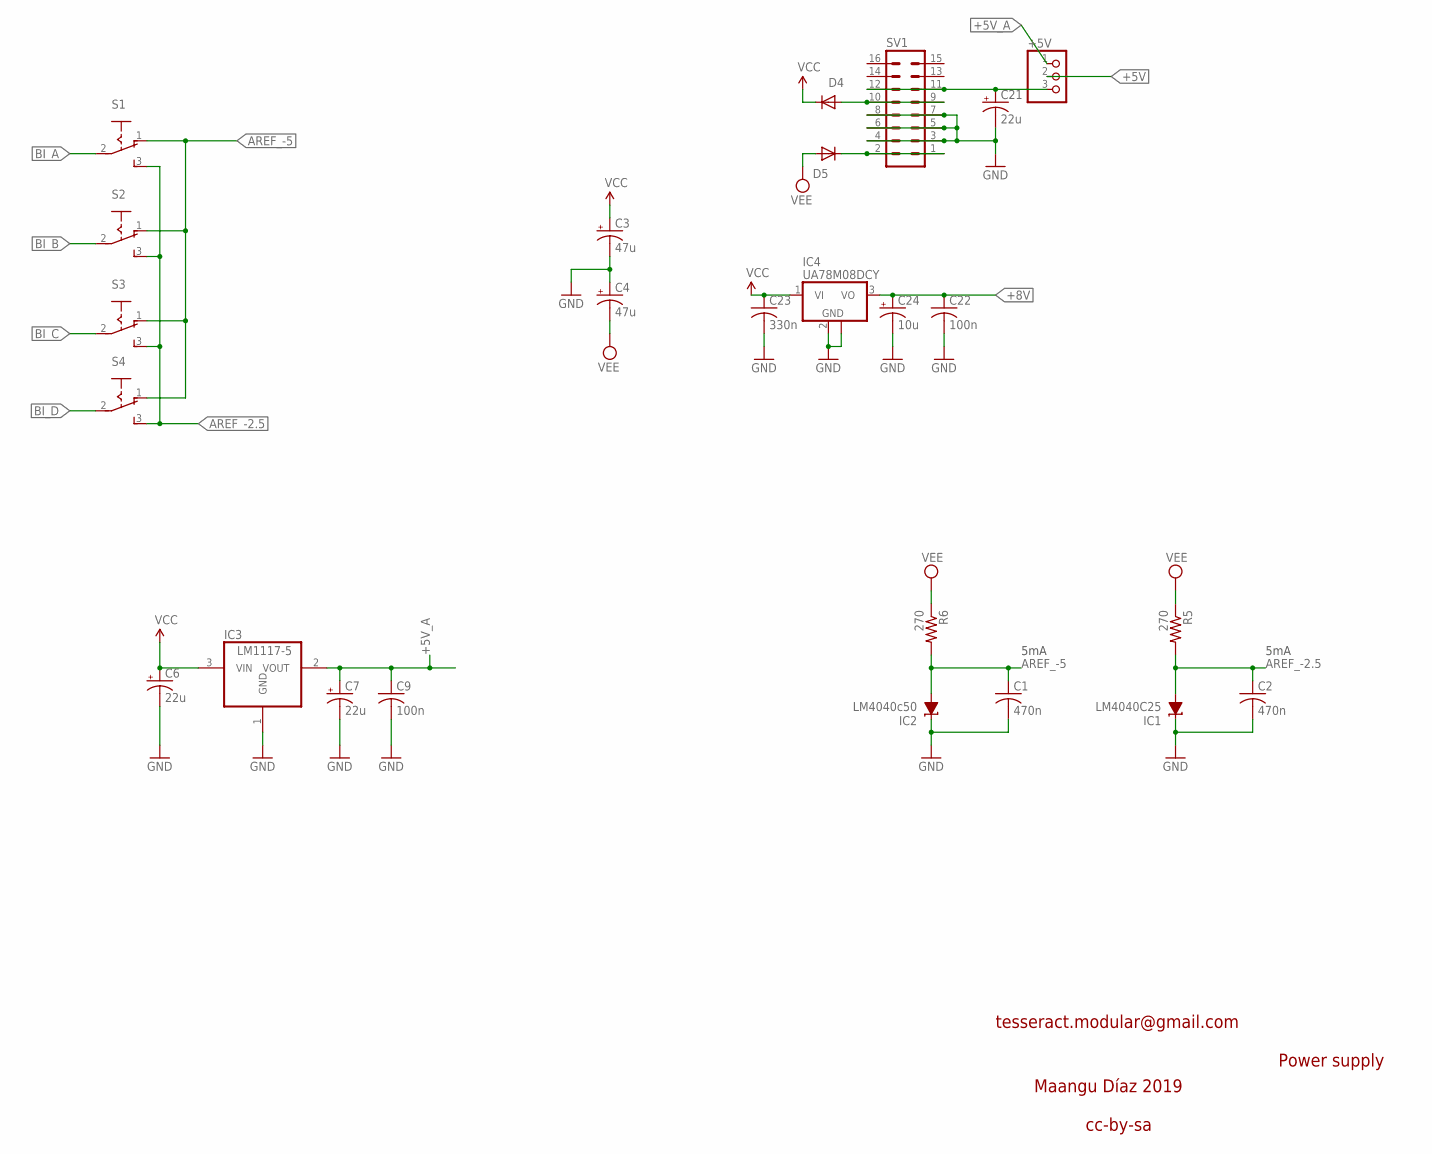
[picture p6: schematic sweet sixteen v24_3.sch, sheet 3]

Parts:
+5V: PINHD-1X3; 1X03
C1, C2: 470n; C0603
C3, C4: 47u; PANASONIC_D
C6, C7, C21: 22u; PANASONIC_D
C9, C22: 100n; C0603
C23: 330n; C0603
C24: 10u; PANASONIC_C
D4, D5: 1N5819HW; SOD123
IC1: LM4040C25; DBZ_R-PDSO-G3
IC2: LM4040c50; DBZ_R-PDSO-G3
IC3: LM1117-5; SOT223
IC4: UA78M08DCY; SOT223
R5, R6: 270; R0603
S1, S2, S3, S4: 255SB-MANGURRIN; 255SB_MANGU
SV1: ML16

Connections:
+5V: +5V.2; also elsewhere on the board
+5V_A: +5V.1, C7.+, C9.1, IC3.2 (VOUT)
+8V: C22.1, C24.+, IC4.3 (VO); also elsewhere on the board
AREF_-2.5: C2.1, IC1.2 (A), R5.2, S1.3 (S), S2.3 (S), S3.3 (S), S4.3 (S)
AREF_-5: C1.1, IC2.2 (A), R6.2, S1.1 (O), S2.1 (O), S3.1 (O), S4.1 (O)
BI_A: S1.2; also elsewhere on the board
BI_B: S2.2; also elsewhere on the board
BI_C: S3.2; also elsewhere on the board
BI_D: S4.2; also elsewhere on the board
GND: C1.2, C2.2, C3.-, C4.+, C6.-, C7.-, C9.2, C21.-, C22.2, C23.2, C24.-, IC1.1 (C), IC2.1 (C), IC3.1 (GND), IC4.2 (GND), IC4.4 (GND), SV1.3, SV1.4, SV1.5, SV1.6, SV1.7, SV1.8; also elsewhere on the board
unnamed: +5V.3, C21.+, SV1.11, SV1.12
unnamed: D4.A, SV1.9, SV1.10
unnamed: D5.C, SV1.1, SV1.2
VCC: C3.+, C6.+, C23.1, D4.C, IC3.3 (VIN), IC4.1 (VI); also elsewhere on the board
VEE: C4.-, D5.A, R5.1, R6.1; also elsewhere on the board

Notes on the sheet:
cc-by-sa
Maangu Díaz 2019
tesseract.modular@gmail.com
Power supply
5mA

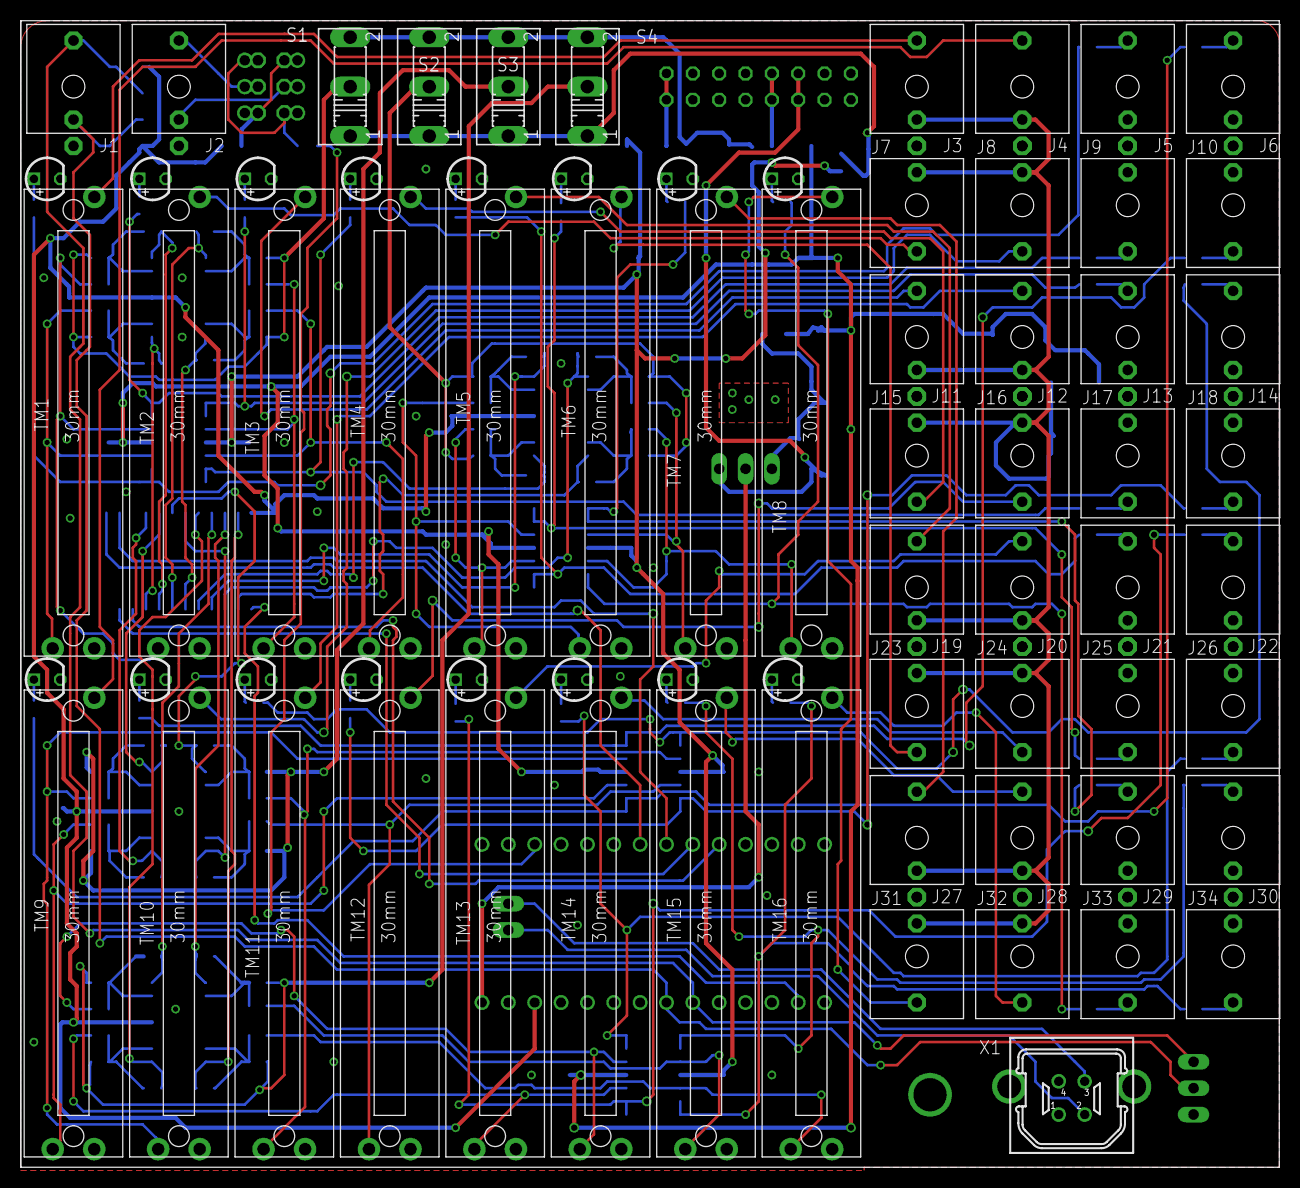
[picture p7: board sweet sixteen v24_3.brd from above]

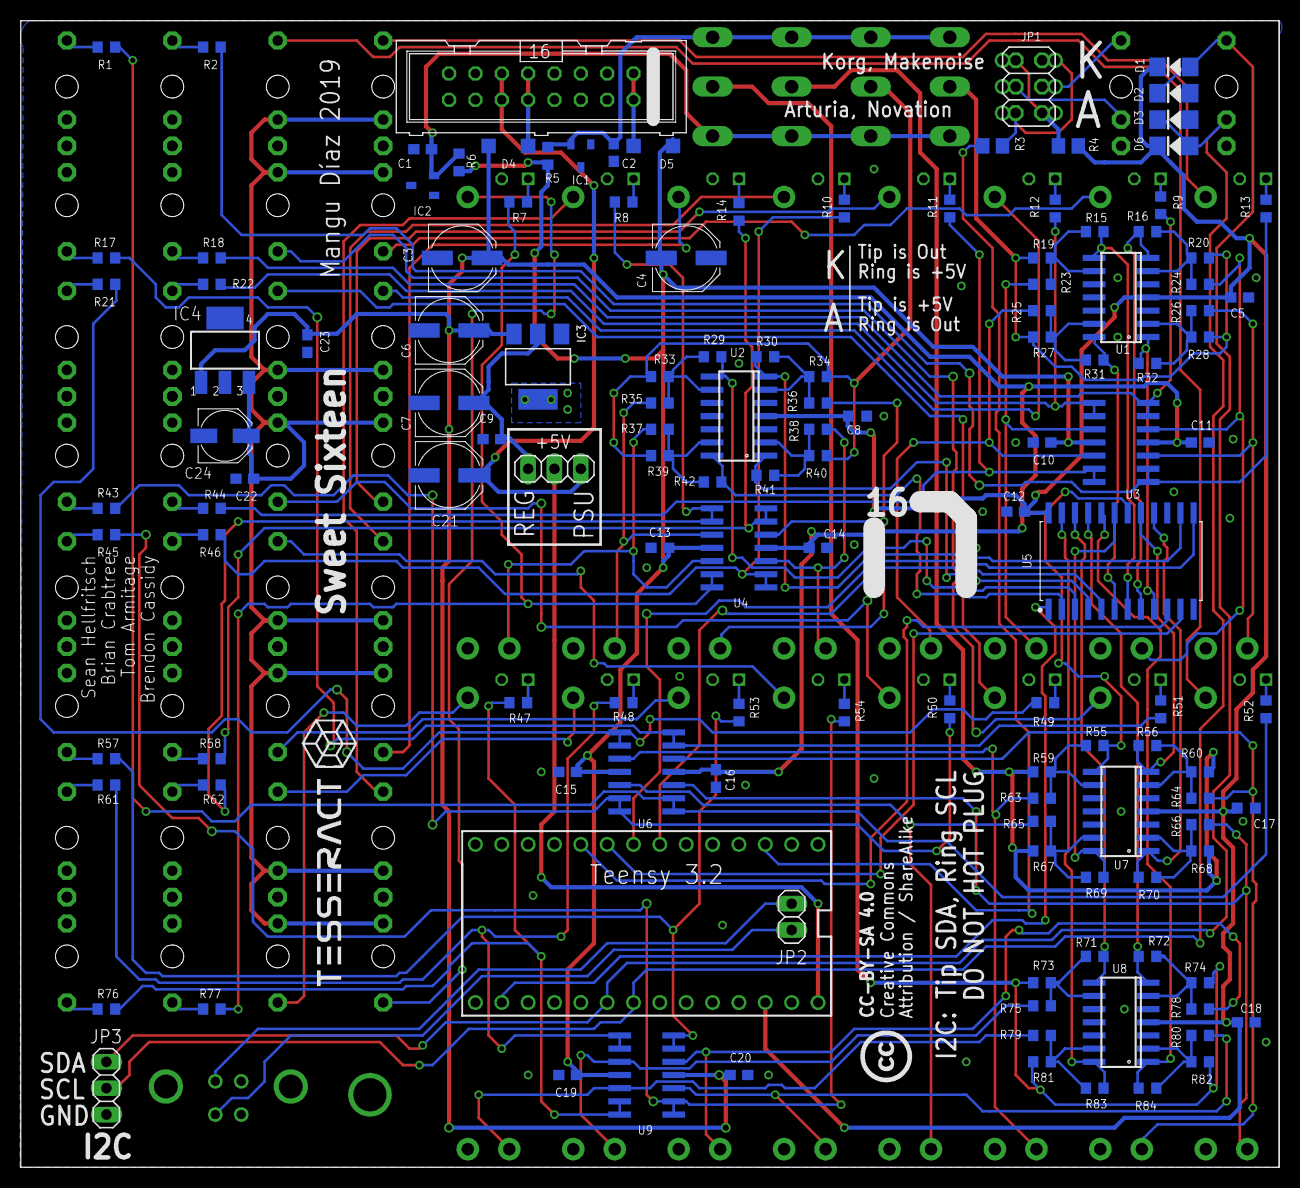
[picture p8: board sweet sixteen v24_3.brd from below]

Board: 2 copper layers, 121.3 x 110.5 mm, 205 parts (133 on the bottom side), 142 nets.

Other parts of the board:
U$1: LOGO

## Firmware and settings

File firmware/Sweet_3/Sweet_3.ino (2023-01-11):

/*
 * 16n Faderbank Firmware
 * (c) 2017,2018,2020 by Brian Crabtree, Sean Hellfritsch, Tom Armitage, and Brendon Cassidy
 * MIT License
 */

/*
 * NOTES:
 * - Hardware MIDI is on pin 1
 * - You **must** also compile this with Tools->USB type set to MIDI or MIDI/Serial (for debugging)
 * - You also should overclock to 120MHz to make it as snappy as possible
 */

/*
 * Most configuration now hpapens via online editor.
 * config.h is mainly for developer configuration.
 */
// modified version for the Tesseract Modular Sweet Sixteen by Mangu Díaz
// changes from the original 16n 2.0.1  firmware from Tom Armitage:
// - calibration of the max fader value is now possible when 'rotated' is active
// - channel numbers are not inverted when 'rotate' is active
// - added support for GESS (it makes midi notes with gates)
// - added pitch bend option (when midiCC 127 is selected)

#include <CD74HC4067.h>
#include <EEPROM.h>
#include <i2c_t3.h>
#include <MIDI.h>
#include <ResponsiveAnalogRead.h>

#include "config.h"
#include "TxHelper.h"

// wrap code to be executed only under DEBUG conditions in D()
#ifdef DEBUG
#define D(x) x
#else
#define D(x)
#endif

#define TO_TR 0x00
#define TO_TR_TOG 0x01
#define TO_TR_TIME 0x02
#define TO_TR_TIME_S 0x03
#define TO_TR_TIME_M 0x04
#define TO_TR_PULSE 0x05
#define TO_TR_POL 0x06

#define TO_CV 0x10
#define TO_CV_SET 0x11
#define TO_CV_SLEW 0x12
#define TO_CV_SLEW_S 0x13
#define TO_CV_SLEW_M 0x14
#define TO_CV_OFF 0x15

#ifdef GESS // only necessary for GESS & midi note thing
// panel led and function button pins:
const int  Led_ = 12;
const int  Butt = 15;
// variables for the functon button
bool _Butt ;
bool old_Butt = HIGH;

// gate in
const int  G[8] = { 3, 0, 22, 20, 21, 23, 4, 2 };
// variables for the gate inputs
bool volatile _G[8] ; // state of the gate input
bool old_G[8];
bool nNote[8];
bool nVelocity[8];
// loop helpers
int ii, k;
// preset management
int nAddress = 100; // memory address for GESS presets
int nPreset;
bool loadActive = false;
bool saveActive = false;
#endif

MIDI_CREATE_DEFAULT_INSTANCE();

// loop helpers
int i, temp;

// midi write helpers
int q, shiftyTemp, notShiftyTemp, lastMidiActivityAt;
int midiDirty = 0;
const int midiFlashDuration = 50;
int ledPin = 13;

// the storage of the values; current is in the main loop; last value is for midi output
int volatile currentValue[channelCount];
int lastMidiValue[channelCount];

// variables to hold configuration
int usbChannels[channelCount];
int trsChannels[channelCount];
int usbCCs[channelCount];
int trsCCs[channelCount];
int legacyPorts[channelCount]; // for V125 only
int flip;
int ledOn;
int ledFlash;
int i2cMaster;

int faderMin;
int faderMax;

// variables for i2c master mode
  // memory of the last unshifted value
  int lastValue[channelCount];

  // the i2c message buffer we are sending
  uint8_t messageBuffer[4];

  // temporary values
  uint16_t valueTemp;
  uint8_t device = 0;
  uint8_t port = 0;

  // master i2c specific stuff
  const int ansibleI2Caddress = 0x20;
  const int er301I2Caddress = 0x31;
  const int txoI2Caddress = 0x60;
  bool er301Present = false;
  bool ansiblePresent = false;
  bool txoPresent = false;


// the thing that smartly smooths the input
ResponsiveAnalogRead *analog[channelCount];

// mux config
CD74HC4067 mux(8, 7, 6, 5);
const int muxMapping[16] = {0, 1, 2, 3, 4, 5, 6, 7, 15, 14, 13, 12, 11, 10, 9, 8};

// MIDI timers
IntervalTimer midiWriteTimer;
IntervalTimer midiReadTimer;
int midiInterval = 1000; // 1ms
bool shouldDoMidiRead = false;
bool shouldDoMidiWrite = false;
bool forceMidiWrite = false;

// helper values for i2c reading and future expansion
int activeInput = 0;
int activeMode = 0;

/*
 * The function that sets up the application
 */
void setup()
{

  D(Serial.println("16n Firmware Debug Mode"));

#ifdef BOOTDELAY // wait some time before continuing boot-up (default is none)
  delay(BOOTDELAY);
#endif

#ifdef GESS
  for (i = 0; i < 8; i++)
  {
    pinMode (G[i], INPUT_PULLUP);
    old_G[i] = HIGH;
    // default GESS settings does not read velocity and note from faders:
    nNote[i] = false;
    nVelocity[i] = false;
  }
  pinMode (Butt, INPUT_PULLUP);
  pinMode (Led_, OUTPUT);
  // boot up pattern
  for ( i = 0; i < 3; i++)
  {
    digitalWrite(Led_, HIGH);
    delay(100);
    digitalWrite(Led_, LOW);
    delay(100);
  }
#endif

  checkDefaultSettings();

  loadSettingsFromEEPROM();
  i2cMaster = EEPROM.read(3) == 1;

  usbMIDI.setHandleSystemExclusive(processIncomingSysex);

  #ifdef V125
  // analog ports on the Teensy for the 1.25 board.
  if(flip) {
    int portsToAssign[] = {A15, A14, A13, A12, A11, A10, A9, A8, A7, A6, A5, A4, A3, A2, A1, A0};
    for(int i=0; i < channelCount; i++) {
      legacyPorts[i] = portsToAssign[i];
    }
  } else {
    int portsToAssign[] = {A0, A1, A2, A3, A4, A5, A6, A7, A8, A9, A10, A11, A12, A13, A14, A15};
    for(int i=0; i < channelCount; i++) {
      legacyPorts[i] = portsToAssign[i];
    }
  }
  #endif

// initialize the TX Helper
#ifdef V125
  TxHelper::UseWire1(true);
#else
  TxHelper::UseWire1(false);
#endif
  TxHelper::SetPorts(16);
  TxHelper::SetModes(4);

  // set read resolution to teensy's 13 usable bits
  analogReadResolution(13);

  // initialize the value storage
  for (i = 0; i < channelCount; i++)
  {
    // analog[i] = new ResponsiveAnalogRead(0, false);

    analog[i] = new ResponsiveAnalogRead(0, true, .0001);
    analog[i]->setAnalogResolution(1 << 13);
    
    // ResponsiveAnalogRead is designed for 10-bit ADCs
    // meanining its threshold defaults to 4. Let's bump that for 
    // our 13-bit adc by setting it to 4 << (13-10)
    analog[i]->setActivityThreshold(32);

    currentValue[i] = 0;
    lastMidiValue[i] = 0;

    if(i2cMaster) {
      lastValue[i] = 0;
    }
  }

// i2c using the default I2C pins on a Teensy 3.2
if(i2cMaster) {

  D(Serial.println("Enabling i2c in MASTER mode"));

#ifdef V125
  Wire1.begin(I2C_MASTER, I2C_ADDRESS, I2C_PINS_29_30, I2C_PULLUP_EXT, 400000);
  Wire1.setDefaultTimeout(10000); // 10ms

  D(Serial.println ("Scanning I2C bus"));
  
  Wire1.begin();
  
  for (byte i = 8; i < 120; i++)
  {
    Wire1.beginTransmission (i);
    if (Wire1.endTransmission () == 0)
      {
        if(i == ansibleI2Caddress) {
          ansiblePresent = true;
          D(Serial.println ("Found ansible"));
        }

        if(i == txoI2Caddress) {
          txoPresent = true;
          D(Serial.println ("Found TXO"));
        }

        if(i == er301I2Caddress) {
          er301Present = true;
          D(Serial.println ("Found ER301"));
        }
      delay (1);  // maybe unneeded?
      } // end of good response
  } // end of for loop

  D(Serial.println ("I2C scan complete."));

#else
  Wire.begin(I2C_MASTER, I2C_ADDRESS, I2C_PINS_18_19, I2C_PULLUP_EXT, 400000);
  Wire.setDefaultTimeout(10000); // 10ms

  D(Serial.println ("Scanning I2C bus"));
  
  Wire.begin();
  
  for (byte i = 8; i < 120; i++)
  {
    Wire.beginTransmission (i);
    if (Wire.endTransmission () == 0)
      {
        if(i == ansibleI2Caddress) {
          ansiblePresent = true;
          D(Serial.println ("Found ansible"));
        }

        if(i == txoI2Caddress) {
          txoPresent = true;
          D(Serial.println ("Found TXO"));
        }

        if(i == er301I2Caddress) {
          er301Present = true;
          D(Serial.println ("Found ER301"));
        }
      delay (1);  // maybe unneeded?
      } // end of good response
  } // end of for loop

  Serial.println ("I2C scan complete.");

#endif

} else {
  // non-master mode

  D(Serial.println("Enabling i2c enabled in SLAVE mode"));

#ifdef V125
  Wire1.begin(I2C_SLAVE, I2C_ADDRESS, I2C_PINS_29_30, I2C_PULLUP_EXT, 400000);
  Wire1.onReceive(i2cWrite);
  Wire1.onRequest(i2cReadRequest);
#else
  Wire.begin(I2C_SLAVE, I2C_ADDRESS, I2C_PINS_18_19, I2C_PULLUP_EXT, 400000);
  Wire.onReceive(i2cWrite);
  Wire.onRequest(i2cReadRequest);
#endif

}

  // turn on the MIDI party
  MIDI.begin();
  midiWriteTimer.begin(writeMidi, midiInterval);
  midiReadTimer.begin(readMidi, midiInterval);

  pinMode(ledPin, OUTPUT);

  if(ledOn) {
    digitalWrite(ledPin, HIGH);
  }
}

/*
 * The main read loop that goes through all of the sliders
 */
void loop()
{
  // this whole chunk makes the LED flicker on MIDI activity - 
  // and inverts that flicker if the power light is on.
  if (ledFlash) {
    if (millis() > (lastMidiActivityAt + midiFlashDuration)) {
      if(ledOn) {
        digitalWrite(ledPin, HIGH);
      } else {
        digitalWrite(ledPin, LOW);
      }
      midiDirty = 0;
    } else {
      if(ledOn) {
        digitalWrite(ledPin, LOW);
      } else {
        digitalWrite(ledPin, HIGH);
      }
    }
  } else {
    if(ledOn) {
      digitalWrite(ledPin, HIGH);
    } else {
      digitalWrite(ledPin, LOW);
    }
  }

  // read loop using the i counter
  for (i = 0; i < channelCount; i++)
  {
#ifdef V125
    temp = analogRead(legacyPorts[i]); // mux goes into A0
#else
    // set mux to appropriate channel
   // if(flip) {
   //   mux.channel(muxMapping[channelCount - i - 1]);
   // } else {
      mux.channel(muxMapping[i]);
   // }

    // read the value
    temp = analogRead(0); // mux goes into A0
#endif

    // put the value into the smoother
    analog[i]->update(temp);

    // read from the smoother, constrain (to account for tolerances), and map it
    temp = analog[i]->getValue();

    if(flip){ 
      temp = 8191 - temp; //       temp = faderMax - temp;
    }

    temp = constrain(temp, faderMin, faderMax);

    temp = map(temp, faderMin, faderMax, 0, 16383);

    // map and update the value
    currentValue[i] = temp;

    #ifdef GESS
    // read the gate inputs
    if (i < 8)
    {
      switch(i)
      {
        case 0:
          _G[i] = digitalReadFast(3);
          break;
        case 1:
          _G[i] = digitalReadFast(0);
          break;
        case 2:
          _G[i] = digitalReadFast(22);
          break;
        case 3:
          _G[i] = digitalReadFast(20);
          break;
        case 4:
          _G[i] = digitalReadFast(21);
          break;
        case 5:
          _G[i] = digitalReadFast(23);
          break;
        case 6:
          _G[i] = digitalReadFast(4);
          break;
        case 7:
          _G[i] = digitalReadFast(2);
          break;
      }
      //_G[i] = digitalRead(G[i]);
      //const int  G[8] = { 3, 0, 22, 20, 21, 23, 4, 2 };
    }
#endif
  }

  if (shouldDoMidiRead)
  {
    doMidiRead();
    noInterrupts();
    shouldDoMidiRead = false;
    interrupts();
  }

  if (shouldDoMidiWrite)
  {
    doMidiWrite();
    noInterrupts();
    shouldDoMidiWrite = false;
    interrupts();
  }
}

/*
 * Tiny function called via interrupt
 * (it's important to catch inbound MIDI messages even if we do nothing with
 * them.)
 */
void readMidi()
{
  shouldDoMidiRead = true;
}

/*
 * Function called when shouldDoMidiRead flag is HIGH
 */

void doMidiRead()
{
  MIDI.read();
  usbMIDI.read();
}

/*
 * Tiny function called via interrupt
 */
void writeMidi()
{
  shouldDoMidiWrite = true;
}

/*
 * The function that writes changes in slider positions out the midi ports
 * Called when shouldDoMidiWrite flag is HIGH
 */
void doMidiWrite()
{
  // write loop using the q counter (
  // (can't use i or temp cuz this might interrupt the reads)
  for (q = 0; q < channelCount; q++)
  {
    notShiftyTemp = currentValue[q];

    // shift for MIDI precision (0-127)
    shiftyTemp = notShiftyTemp >> 7;

    // if there was a change in the midi value
    // if ((shiftyTemp != lastMidiValue[q]) || forceMidiWrite)
    if (( shiftyTemp != lastMidiValue[q]) || ((( usbCCs[q] == 127 ) || ( trsCCs[q] == 127 )) && ( notShiftyTemp != lastValue[q] )) || forceMidiWrite )
    {
      if(ledFlash && !midiDirty) {
        lastMidiActivityAt = millis();
        midiDirty = 1;
      }

      // only if GESS is not using the faders we send midiCC etc...
#ifdef GESS
      if ((( q < 8 ) && (nNote[q] == false)) || (( q > 7 ) && (nVelocity[q - 8] == false)))
      {
#endif

#ifdef PITCHBEND
        if ( usbCCs[q] == 127 )
        {
          usbMIDI.sendPitchBend((notShiftyTemp - 8192), usbChannels[q]);          
        }
        else
#endif        
        {          
          // send the message over USB and physical MIDI
          usbMIDI.sendControlChange(usbCCs[q], shiftyTemp, usbChannels[q]);
        }
#ifdef PITCHBEND
        if ( trsCCs[q] == 127 )
        { 
          MIDI.sendPitchBend((notShiftyTemp - 8192), trsChannels[q]);
        }
        else
#endif
        {
          // send the message over physical MIDI
          MIDI.sendControlChange(trsCCs[q], shiftyTemp, trsChannels[q]);
        }     

#ifdef GESS
      }
#endif

      // store the shifted value for future comparison
      lastMidiValue[q] = shiftyTemp;

      // D(Serial.printf("MIDI[%d]: %d\n", q, shiftyTemp));
    }

#ifdef GESS
    // Midi Note
    if ((q > 7) && (_G[q - 8] != old_G[q - 8])) // only if the gate input has changed we do this:
    {
      k = ( q - 8) ;
      if ( _G[k] == LOW ) //note ON
      {
        if (nNote[k] == true) // taking the note value from the upper row of faders instead of a fixed value
        {
          _nNote[k] = lastMidiValue[k];
        }
        if (nVelocity[k] == true) // taking the midi velocity from the lower row instead instead of a fixed value
        {
          _nVelocity[k] = lastMidiValue[q];
        }
        MIDI.sendNoteOn(_nNote[k], _nVelocity[k], _nChannel[k] ); // at the moment channels are 1 to 8 preassigned
        usbMIDI.sendNoteOn(_nNote[k], _nVelocity[k], _nChannel[k] );
        // ER-301
        if(er301Present) {
           // https://github.com/odevices/er-301/blob/develop/mods/teletype/Dispatcher.cpp
           // SC.TR 1-n α --> Set TR value to α (0/1)
           // commandTRSet(delay, getPort(msg), getValue(msg));
           sendi2c(er301I2Caddress, 0, TO_TR, q-8, 1);
        }
        
      }
      else //Note Off
      {
        MIDI.sendNoteOff(_nNote[k], _nVelocity[k], _nChannel[k] );
        usbMIDI.sendNoteOff(_nNote[k], _nVelocity[k], _nChannel[k] );
        if(er301Present) {
           sendi2c(er301I2Caddress, 0, TO_TR, q-8, 0);
        }
        
      }
      old_G[k] = _G[k];
    }  //end of midi note code
#endif

    if(i2cMaster) {

      // we send out to all three supported i2c slave devices
      // keeps the firmware simple :)

      if (notShiftyTemp != lastValue[q])
      {
        D(Serial.printf("i2c Master[%d]: %d\n", q, notShiftyTemp));

        // for 4 output devices
        port = q % 4;
        device = q / 4;

        // TXo
        if(txoPresent) {
          sendi2c(txoI2Caddress, device, 0x11, port, notShiftyTemp);
        }

        // ER-301
        if(er301Present) {
          sendi2c(er301I2Caddress, 0, TO_CV_SET, q, notShiftyTemp);
        }

        // ANSIBLE
        if(ansiblePresent) {
          sendi2c(0x20, device << 1, 0x06, port, notShiftyTemp);
        }

        lastValue[q] = notShiftyTemp;
      }
    }
  }
  forceMidiWrite = false;

  #ifdef GESS
  // button read to load & save presets etc:
  _Butt = digitalReadFast(Butt);

  if (_Butt != old_Butt) // change in the button
  {
    if (_Butt == true )
    {
      // button depressed, switch the load preset mode
      saveActive = false;
      loadActive = !loadActive;
      digitalWrite(Led_, loadActive);
    }
    else
    {
      saveActive = true;
    }
    old_Butt = _Butt;
  }

  if ( saveActive ==  true )  // save preset if any of the GESS buttons/triggers is active
  {
    for (ii = 0; ii < 8; ii++)
    {
      if (_G[ii] == LOW)
      {
        savePreset(ii);
        saveActive = false;
        loadActive = true; // when the button is released it will become false ;-)
        digitalWrite(Led_, HIGH);
      }
    }
  }

  if (( loadActive == true ) && ( _Butt == HIGH ))
  {
    for (ii = 0; ii < 8; ii++)
    {
      if (_G[ii] == LOW)
      {
        loadPreset(ii);
        loadActive = false;
        digitalWrite(Led_, LOW);
      }
    }
  }// end of the preset management
  
#endif
} // end of doMidiWrite

/*
 * Sends an i2c command out to a slave when running in master mode
 */
void sendi2c(uint8_t model, uint8_t deviceIndex, uint8_t cmd, uint8_t devicePort, int value)
{

  valueTemp = (uint16_t)value;
  messageBuffer[2] = valueTemp >> 8;
  messageBuffer[3] = valueTemp & 0xff;

#ifdef V125
  Wire1.beginTransmission(model + deviceIndex);
  messageBuffer[0] = cmd;
  messageBuffer[1] = (uint8_t)devicePort;
  Wire1.write(messageBuffer, 4);
  Wire1.endTransmission();
#else
  Wire.beginTransmission(model + deviceIndex);
  messageBuffer[0] = cmd;
  messageBuffer[1] = (uint8_t)devicePort;
  Wire.write(messageBuffer, 4);
  Wire.endTransmission();
#endif
}

/*
 * The function that responds to a command from i2c.
 * In the first version, this simply sets the port to be read from.
 */
void i2cWrite(size_t len)
{

  D(Serial.printf("i2c Write (%d)\n", len));

  // parse the response
  TxResponse response = TxHelper::Parse(len);

  // true command our setting of the input for a read?
  if (len == 1)
  {

    // use a helper to decode the command
    TxIO io = TxHelper::DecodeIO(response.Command);

    D(Serial.printf("Port: %d; Mode: %d [%d]\n", io.Port, io.Mode, response.Command));

    // this is the single byte that sets the active input
    activeInput = io.Port;
    activeMode = io.Mode;
  }
  else
  {
    // act on the command
    actOnCommand(response.Command, response.Output, response.Value);
  }
}

/*
 * The function that responds to read requests over i2c.
 * This uses the port from the write request to determine which slider to send.
 */
void i2cReadRequest()
{

  D(Serial.print("i2c Read\n"));

  // get and cast the value
  uint16_t shiftReady = 0;
  switch (activeMode)
  {
  case 1:
    shiftReady = (uint16_t)currentValue[activeInput];
    break;
  case 2:
    shiftReady = (uint16_t)currentValue[activeInput];
    break;
  default:
    shiftReady = (uint16_t)currentValue[activeInput];
    break;
  }

  D(Serial.printf("delivering: %d; value: %d [%d]\n", activeInput, currentValue[activeInput], shiftReady));

// send the puppy as a pair of bytes
#ifdef V125
  Wire1.write(shiftReady >> 8);
  Wire1.write(shiftReady & 255);
#else
  Wire.write(shiftReady >> 8);
  Wire.write(shiftReady & 255);
#endif
}

/*
 * Future function if we add more i2c capabilities beyond reading values.
 */
void actOnCommand(byte cmd, byte out, int value) {}

#ifdef GESS
void loadPreset(int nPreset)  //read eeprom
{
  nAddress = 100 + ( nPreset * 16 );
  for ( ii = 0; ii < 8; ii++ ) //gates
  {
    _nNote[ii] = EEPROM.read(nAddress);
    if (_nNote[ii] == 0)
    {
      nNote[ii] = true;
    }
    else
    {
      nNote[ii] = false;
    }
    nAddress++ ;
    _nVelocity[ii] = EEPROM.read(nAddress);
    if (_nVelocity[ii] == 0)
    {
      nVelocity[ii] = true;
    }
    else
    {
      nVelocity[ii] = false;
    }
    nAddress++ ;
    //  _nChannel[ii] = EEPROM.read(nAddress);
    //   nAddress++ ;
  }
}
void savePreset(int nPreset)
{
  nAddress = 100 + ( nPreset * 16 );
  for ( ii = 0; ii < 8; ii++ ) //gates
  {

    if (lastMidiValue[ii] == 0)
    {
      nNote[ii] = true;
      _nNote[ii] = 0;
    }
    else
    {
      nNote[ii] = false;
    }

    EEPROM.write(nAddress, _nNote[ii]);
    nAddress++;

    if (lastMidiValue[ii + 8] == 0)
    {
      nVelocity[ii] = true;
      _nVelocity[ii] = 0;
    }
    else
    {
      nVelocity[ii] = false;
    }

    EEPROM.write(nAddress, _nVelocity[ii]);
    nAddress++;
    // midi channel setting are not saved because they're preassigned
    //    EEPROM.write(nAddress, _nChannel[ii]);
    //    nAddress++;
  }
}
#endif

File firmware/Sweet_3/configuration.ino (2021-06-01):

/*
 * 16n Faderbank EEPROM-based configuration
 * (c) 2020 by Tom Armitage
 * MIT License
 */


// for pitch bend use CC value 127
const int defaultUSBCCs[] = {32, 33, 34, 35, 36, 37, 38, 39, 40, 41, 42, 43, 44, 45, 46, 47};
const int defaultTRSCCs[] = {32, 33, 34, 35, 36, 37, 38, 39, 40, 41, 42, 43, 44, 45, 46, 47};

const int defaultUSBChannels[] = {1, 1, 1, 1, 1, 1, 1, 1, 1, 1, 1, 1, 1, 1, 1, 1};
const int defaultTRSChannels[] = {1, 1, 1, 1, 1, 1, 1, 1, 1, 1, 1, 1, 1, 1, 1, 1};

void checkDefaultSettings() {
  // if byte1 of EEPROM is FF for whatever reason, let's assume the machine needs initializing
  int firstByte = EEPROM.read(0x00);

  if(firstByte > 0x01) {
    D(Serial.println("First Byte is > 0x01, probably needs initialising"));
    initializeFactorySettings();
  } else {
    D(Serial.print("First Byte is set to: "));
    D(printHex(firstByte));
    D(Serial.println());
    byte buffer[80];
    readEEPROMArray(0, buffer, 80);
    D(Serial.println("Config found:"));
    D(printHexArray(buffer, 80));
  }
}

 void initializeFactorySettings() {
  // set default config flags (LED ON, LED DATA, ROTATE, etc)
  // fadermin/max are based on "works for me" for twra2. Your mileage may vary.
  EEPROM.write(0,0); // LED ON
  EEPROM.write(1,0); // LED DATA
  EEPROM.write(2,1); // ROTATE   EEPROM.write(2,0)
  EEPROM.write(3,1); // I2C follower by default EEPROM.write(3,0)
  EEPROM.write(4,20); // fadermin LSB
  EEPROM.write(5,0); // fadermin MSB
  EEPROM.write(6,36); // fadermax LSB
  EEPROM.write(7,63); // fadermax MSB

  // set default USB channels
  for(int i = 0; i < channelCount; i++) {
    int baseAddress = 16;
    int writeAddress = baseAddress + i;
    EEPROM.write(writeAddress, defaultUSBChannels[i]);
  }

  // set default TRS channels
  for(int i = 0; i < channelCount; i++) {
    int baseAddress = 32;
    int writeAddress = baseAddress + i;
    EEPROM.write(writeAddress, defaultTRSChannels[i]);
  }

  // set default USB channel ccs
  for(int i = 0; i < channelCount; i++) {
    int baseAddress = 48;
    int writeAddress = baseAddress + i;
    EEPROM.write(writeAddress, defaultUSBCCs[i]);
  }

  // set default TRS channel ccs
  for(int i = 0; i < channelCount; i++) {
    int baseAddress = 64;
    int writeAddress = baseAddress + i;
    EEPROM.write(writeAddress, defaultTRSCCs[i]);
  }

  // serial dump that config.
  byte buffer[80];
  readEEPROMArray(0,buffer,80);
  D(Serial.println("Config Instantiated."));
  D(printHexArray(buffer, 80));
}

void loadSettingsFromEEPROM() {
  // load usb channels
  for(int i = 0; i < channelCount; i++) {
    int baseAddress = 16;
    int readAddress = baseAddress + i;
    usbChannels[i] = EEPROM.read(readAddress);
  }

  D(Serial.println("USB Channels loaded:"));
  D(printIntArray(usbChannels,channelCount));

  // load TRS channels
  for(int i = 0; i < channelCount; i++) {
    int baseAddress = 32;
    int readAddress = baseAddress + i;
    trsChannels[i] = EEPROM.read(readAddress);
  }

  D(Serial.println("TRS Channels loaded:"));
  D(printIntArray(trsChannels,channelCount));

  // load USB ccs
  for(int i = 0; i < channelCount; i++) {
    int baseAddress = 48;
    int readAddress = baseAddress + i;
    usbCCs[i] = EEPROM.read(readAddress);
  }

  D(Serial.println("USB CCs loaded:"));
  D(printIntArray(usbCCs,channelCount));


  // load TRS ccs
  for(int i = 0; i < channelCount; i++) {
    int baseAddress = 64;
    int readAddress = baseAddress + i;
    trsCCs[i] = EEPROM.read(readAddress);
  }

  D(Serial.println("TRS CCs loaded:"));
  D(printIntArray(trsCCs,channelCount));

  // load other config
  ledOn = EEPROM.read(0);
  ledFlash = EEPROM.read(1);
  flip = EEPROM.read(2);

  // i2cMaster only read at startup

  int faderminLSB = EEPROM.read(4);
  int faderminMSB = EEPROM.read(5);

  D(Serial.print ("Setting fadermin to "));
  D(Serial.println((faderminMSB << 7) + faderminLSB));
  faderMin = (faderminMSB << 7) + faderminLSB;

  int fadermaxLSB = EEPROM.read(6);
  int fadermaxMSB = EEPROM.read(7);

  D(Serial.print ("Setting fadermax to "));
  D(Serial.println((fadermaxMSB << 7) + fadermaxLSB));
  faderMax = (fadermaxMSB << 7) + fadermaxLSB;
}

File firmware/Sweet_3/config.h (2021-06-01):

/*
 * 16n Faderbank Firmware Configuration
 * (c) 2017,2018,2020 by Brian Crabtree, Sean Hellfritsch, Tom Armitage, and Brendon Cassidy
 * MIT License
 */


/*
 * firmware metadata
 */

int MAJOR_VERSION = 0x02;
int MINOR_VERSION = 0x00;
int POINT_VERSION = 0x01;

/*
 * device metadata
 */

#if defined(__MKL26Z64__) || defined(__MK20DX128__) || defined(_LC_DEBUG)
const int DEVICE_ID = 0x03; // 16nLC, do not change, needed by editor
#else
const int DEVICE_ID = 0x02; // 16n, do not change, needed by editor
#endif

// restricts output to only channel 1 for development purposes
// #define DEV 1

// activates printing of debug messages
// #define DEBUG 1

// enables legacy compatibility with non-multiplexer boards
// #define V125

// define startup delay in milliseconds
// largely only needed for "Sweet-Sixteen" type devices
#define BOOTDELAY 10000

// allow the Tsesseract Modular GESS & midi note implementation:
#define GESS 1

#ifdef GESS
// default GESS settings (midi note, velocity and channel):
byte _nNote[8] = { 30, 40, 50, 60, 70, 80, 90, 100 };
byte _nVelocity[8] = { 120, 120, 120, 120, 120, 120, 120, 120 };
byte _nChannel[8] = { 1, 2, 3, 4, 5, 6, 7, 8 };
#endif

// uncomment this to allow PITCHBEND for controller 127
#define PITCHBEND 1

// I2C Address for Faderbank. 0x34 unless you ABSOLUTELY know what you are doing.
#define I2C_ADDRESS 0x34

#ifdef DEV

const int channelCount = 1;
const int ports[] = {A0};

#else

const int channelCount = 16;

#endif

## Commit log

2020-02-29 Add files via upload
    in this version a boot-up delay time has been added to make it work with the ER-301, when using PitchBend in the USB out a different midi CC can be used in the midi TRS out (and vice versa) and it do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
2020-02-29 Add files via upload
    added bill of materials
    [Sweet Sixteen BOM.csv]
2020-05-02 various bugs fixed
    -fixed error when compiling without the #master option
    -fixed the values being different in the i2c for the channels with PitchBend is selected as midi controller
    -code reduced and simplified
    [_16n_faderbank_firmware_Sweet.ino, config.h]

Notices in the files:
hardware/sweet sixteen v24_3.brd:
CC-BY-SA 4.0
